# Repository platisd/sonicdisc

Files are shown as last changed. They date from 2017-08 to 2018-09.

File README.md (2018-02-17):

# SonicDisc
A 360° ultrasonic scanner that talks over I2C using an Atmega328P and eight HC-SR04 ultrasonic sensors.

sonicdisc

## Overview
SonicDisc is a sensor that allows you to sense your surroundings. It utilizes 8 ultrasound sensors (HC-SR04) placed at 45° angle from each other, that can measure distances from practically every direction. It can be used in hobby-grade automotive applications, e.g. autonomous driving, obstacle detection etc or wherever quickly determining surrounding distances is relevant.

The sensor transmits the collected data over I2C and uses a separate line to signal, with a short pulse, the existence of a new set of measurements. It can be mounted on top of an Arduino UNO or used standalone. Due to the nature of the HC-SR04 sensors, the measurements can be noisy, therefore it is suggested that they are filtered. A basic Arduino example that receives and filters the incoming data can be found in [examples/SonicDiscReader](examples/SonicDiscReader).

You can find the software running on the SonicDisc in [firmware/](firmware/), the PCB design in Eagle CAD format inside [hardware/](hardware/eagle) and more sample applications using the SonicDisc in [examples](examples/).

Read the story behind the module at [platis.solutions](https://platis.solutions/blog/2017/08/27/sonicdisc-360-ultrasonic-scanner/).

## How does it work
SonicDisc is comprised of an Atmega328P microcontroller that triggers all the ultrasound sensors at the same time, receives the echo pulses via pin change interrupts and then proceeds to calculate the detected distances. The use of interrupts, in contrast to how the HC-SR04 sensors are typically utilized, enable us to conduct all measurements at the "same" time which translates into new sets of `8` measurements every `10 milliseconds`.

As an I2C slave, whenever a new set of measurements is ready to be transmitted, a short pulse is sent over the `INT` pin, prompting the master to request the data. In other words the I2C master reading the data from the SonicDisc, does not have to poll but merely wait for the indicative signal and then make the I2C request. Despite not suggested, it is possible to use SonicDisc without connecting the `INT` pin to an interrupt, however the master will not be able to assure the existence of a new data.

## How to connect
| SonicDisc | Host MCU  |
| :----: |:----: |
| VCC |  5V |
| GND |  GND |
| SDA |  SDA |
| SCL |  SCL |
| INT |  ISR |

If you are mounting the SonicDisc on top of an Arduino UNO as a shield, you only have to (optionally but suggested) connect the `INT` signal to an ISR pin.

## I2C protocol
SonicDisc communicates using the I2C bus as a slave, meaning that it receives data from a master and responds to data requests.

### Address
SonicDisc's I2C address is currently hardcoded to `0x09`.

### Set operational state
SonicDisc has two operational states between which you can switch.

| **Action** | **Byte to send**  | **Notes** |
| :---: |:---: | :----: |
| Set state to `STANDBY` | 0x0A | SonicDisc's initial state |
| Set state to `MEASURING` | 0x0B | Set to this state to start the measurements |

**Arduino example:**
```arduino
Wire.beginTransmission(0x09);
Wire.write(0x0B); // Instruct SonicDisc to start measuring
Wire.endTransmission(0x09);
```
### Get data
SonicDisc responds to I2C requests with packages of `9` bytes that include an error code and sensor measurements. A typical package structure is described below.

Regarding the error codes, when the first byte is a `0` then everything went well and the trailing measurements are valid. If it is `1`, it means that this set of data has already been transmitted and a measurement is currently under way. You will encounter this if you poll the sensor fast enough, without taking into consideration the `INT` signal which indicates SonicDisc is ready to transmit new data. Finally, `2` designates that the module is in standby state and no measurements are being conducted.

| **Byte Index** | **Range** | **Purpose** | **Notes** |
| :----: |:----: | :----: | :----: |
| 0 |  0-2 | Error code | **0**: No error, **1**: Incomplete measurement, **2**: In standby state |
| 1 |  0-255  | Ultrasonic 0  | **0**: Error in measurement, **1**: TBD, **2-255**: Valid distance (cm) |
| 2 |  0-255  | Ultrasonic 1  | **0**: Error in measurement, **1**: TBD, **2-255**: Valid distance (cm) |
| 3 |  0-255  | Ultrasonic 2  | **0**: Error in measurement, **1**: TBD, **2-255**: Valid distance (cm) |
| 4 |  0-255  | Ultrasonic 3  | **0**: Error in measurement, **1**: TBD, **2-255**: Valid distance (cm) |
| 5 |  0-255  | Ultrasonic 4  | **0**: Error in measurement, **1**: TBD, **2-255**: Valid distance (cm) |
| 6 |  0-255  | Ultrasonic 5  | **0**: Error in measurement, **1**: TBD, **2-255**: Valid distance (cm) |
| 7 |  0-255  | Ultrasonic 6  | **0**: Error in measurement, **1**: TBD, **2-255**: Valid distance (cm) |
| 8 |  0-255  | Ultrasonic 7  | **0**: Error in measurement, **1**: TBD, **2-255**: Valid distance (cm) |

**Arduino example:**

```arduino
const unsigned int PACKET_SIZE = 9;
unsigned int packet[PACKET_SIZE] = {0};
unsigned int packetIndex = 0;
Wire.requestFrom(0x09, PACKET_SIZE);
while (Wire.available() && packetIndex < PACKET_SIZE) {
    i2cInput[packetIndex++] = Wire.read();
}
// Now the packet[] array holds the incoming data from SonicDisc
```

## Build one yourself
Below you can find the necessary components to build a SonicDisc yourself:

* [SonicDisc PCB](https://www.pcbway.com/project/shareproject/SonicDisc___A_360__ultrasonic_scanner__rev_1_.html)
* 8 x HC-SR04
* 1 x Atmega328P-PU
* 2 x 22pF capacitors
* 3 x 0.1uF capacitors
* 1 x 1206 LED
* 1 x 1206 220Ω resistor
* 3 x 4.7KΩ resistor
* 1 x 5-pin header
* 1 x 4-pin header
* 1 x tactile switch
* 1 x 16MHz oscillator
* 1 x ISCP pin header
* 1 x 10-pin stackable header
* 2 x 8-pin stackable header
* 1 x 6-pin stackable header

## Derivative works
* [Arduino Pro Mini version with single plane sensors](https://github.com/richardFirth/sonicdisc) by [richardFirth](https://github.com/richardFirth).

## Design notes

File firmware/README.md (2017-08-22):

# SonicDisc
The firmware running on the Atmega328P of the SonicDisc.

## Overview
SonicDisc sends a trigger pulse to all the attached ultrasonic sensors and then uses interrupts to log down when the echo signals were received and the detected distances are calculated. If the echo has not arrived before the specified time, then the measurement is nulled.

The results of the measurements are being made available over the I2C interface when they are being sent as a package along with an error code. Additionally, a short pulse (3 μsec) is generated in order to notify other microcontrollers that new data are available.

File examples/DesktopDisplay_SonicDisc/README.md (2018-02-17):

# DesktopDisplay_SonicDisc
This Processing3 sketch provides a visual interface for the data produced by SonicDiskReader. Connect an arduino with a SonicDisc to the computer, and then open the processing sketch. Use the number keys to select the COM port for the arduino, and the output data from SonicDiskReader will be displayed in a ring.

The distance of each circle will be proportional to the distance from the SonicDisc.

Processing3 can be downloaded from https://processing.org/. Then this sketch can be run.

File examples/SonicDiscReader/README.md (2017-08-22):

# Sonic Disc Reader
A sample Arduino sketch that demonstrates how to use the SonicDisc when attached via I2C.

Primarily, it is shown how to:
* Initiate SonicDisc measurements
* Read data
* Filter data based on variance

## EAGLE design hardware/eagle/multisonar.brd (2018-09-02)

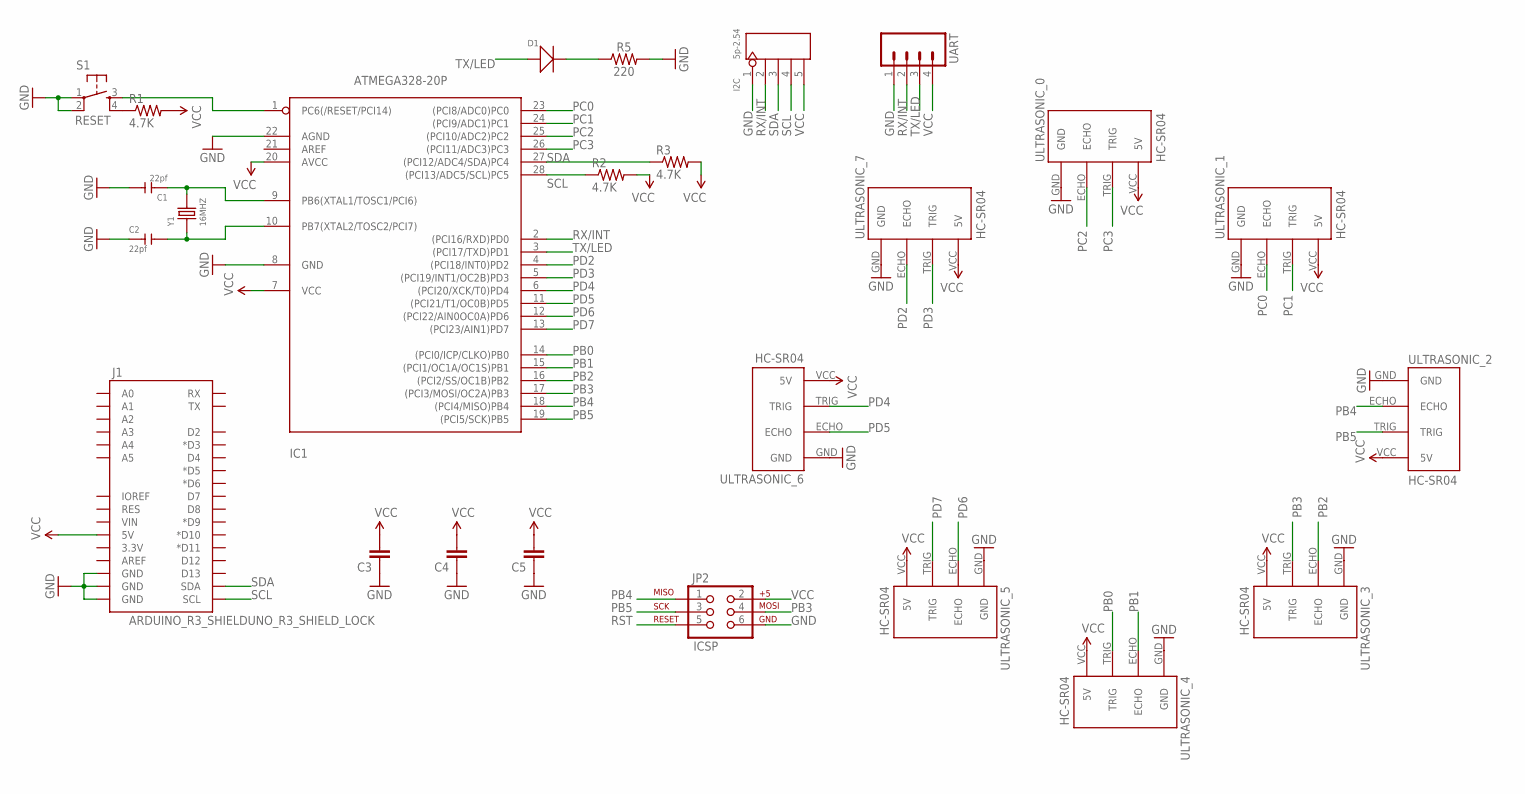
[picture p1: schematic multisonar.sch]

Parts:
C1, C2: 22pf; CERAMIC-2.54
C3, C4, C5: 0.1UF-50V-20%(PTH)KIT-EZ; CAP-PTH-SMALL-KIT
D1: DIODE'1206'; SOD-123
I2C: 5p-2.54; H5-2.54
IC1: ATMEGA328-20P; DIL28-3
J1: ARDUINO_R3_SHIELDUNO_R3_SHIELD_LOCK; UNO_R3_SHIELD_LOCK
JP2: ICSP; 2X3_LOCK
R1, R2, R3: 4.7K; AXIAL-0.3EZ
R5: 220; 1206
S1: RESET; TAC-SWITCH-PTH
UART: M04PTH; 1X04
ULTRASONIC_0, ULTRASONIC_1, ULTRASONIC_2, ULTRASONIC_3, ULTRASONIC_4, ULTRASONIC_5, ULTRASONIC_6, ULTRASONIC_7: HC-SR04; HC-SR04_FOOTPRINT
Y1: 16MHZ; HC49US

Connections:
GND: C1.2, C2.1, C3.1, C4.1, C5.1, I2C.1, IC1.8 (GND), IC1.22 (AGND), J1.GND@0 (GND), J1.GND@1 (GND), J1.GND@2 (GND), JP2.6, R5.2, S1.1, S1.2, UART.1, ULTRASONIC_0.GND, ULTRASONIC_1.GND, ULTRASONIC_2.GND, ULTRASONIC_3.GND, ULTRASONIC_4.GND, ULTRASONIC_5.GND, ULTRASONIC_6.GND, ULTRASONIC_7.GND
unnamed: R1.P$1 (1), S1.4
unnamed: D1.-, R5.1
unnamed: C1.1, IC1.9 (PB6(XTAL1/TOSC1/PCI6)), Y1.2
unnamed: C2.2, IC1.10 (PB7(XTAL2/TOSC2/PCI7)), Y1.1
PB0: IC1.14 ((PCI0/ICP/CLKO)PB0), ULTRASONIC_4.TRIG
PB1: IC1.15 ((PCI1/OC1A/OC1S)PB1), ULTRASONIC_4.ECHO
PB2: IC1.16 ((PCI2/SS/OC1B)PB2), ULTRASONIC_3.ECHO
PB3: IC1.17 ((PCI3/MOSI/OC2A)PB3), JP2.4, ULTRASONIC_3.TRIG
PB4: IC1.18 ((PCI4/MISO)PB4), JP2.1, ULTRASONIC_2.ECHO
PB5: IC1.19 ((PCI5/SCK)PB5), JP2.3, ULTRASONIC_2.TRIG
PC0: IC1.23 ((PCI8/ADC0)PC0), ULTRASONIC_1.ECHO
PC1: IC1.24 ((PCI9/ADC1)PC1), ULTRASONIC_1.TRIG
PC2: IC1.25 ((PCI10/ADC2)PC2), ULTRASONIC_0.ECHO
PC3: IC1.26 ((PCI11/ADC3)PC3), ULTRASONIC_0.TRIG
PD2: IC1.4 ((PCI18/INT0)PD2), ULTRASONIC_7.ECHO
PD3: IC1.5 ((PCI19/INT1/OC2B)PD3), ULTRASONIC_7.TRIG
PD4: IC1.6 ((PCI20/XCK/T0)PD4), ULTRASONIC_6.TRIG
PD5: IC1.11 ((PCI21/T1/OC0B)PD5), ULTRASONIC_6.ECHO
PD6: IC1.12 ((PCI22/AIN0OC0A)PD6), ULTRASONIC_5.ECHO
PD7: IC1.13 ((PCI23/AIN1)PD7), ULTRASONIC_5.TRIG
RST: IC1.1 (PC6(/RESET/PCI14)), JP2.5, S1.3
RX/INT: I2C.2, IC1.2 ((PCI16/RXD)PD0), UART.2
SCL: I2C.4, IC1.28 ((PCI13/ADC5/SCL)PC5), J1.SCL, R2.P$1 (1)
SDA: I2C.3, IC1.27 ((PCI12/ADC4/SDA)PC4), J1.SDA, R3.P$1 (1)
TX/LED: D1.+, IC1.3 ((PCI17/TXD)PD1), UART.3
VCC: C3.2, C4.2, C5.2, I2C.5, IC1.7 (VCC), IC1.20 (AVCC), J1.5V, JP2.2, R1.P$2 (2), R2.P$2 (2), R3.P$2 (2), UART.4, ULTRASONIC_0.VCC (5V), ULTRASONIC_1.VCC (5V), ULTRASONIC_2.VCC (5V), ULTRASONIC_3.VCC (5V), ULTRASONIC_4.VCC (5V), ULTRASONIC_5.VCC (5V), ULTRASONIC_6.VCC (5V), ULTRASONIC_7.VCC (5V)

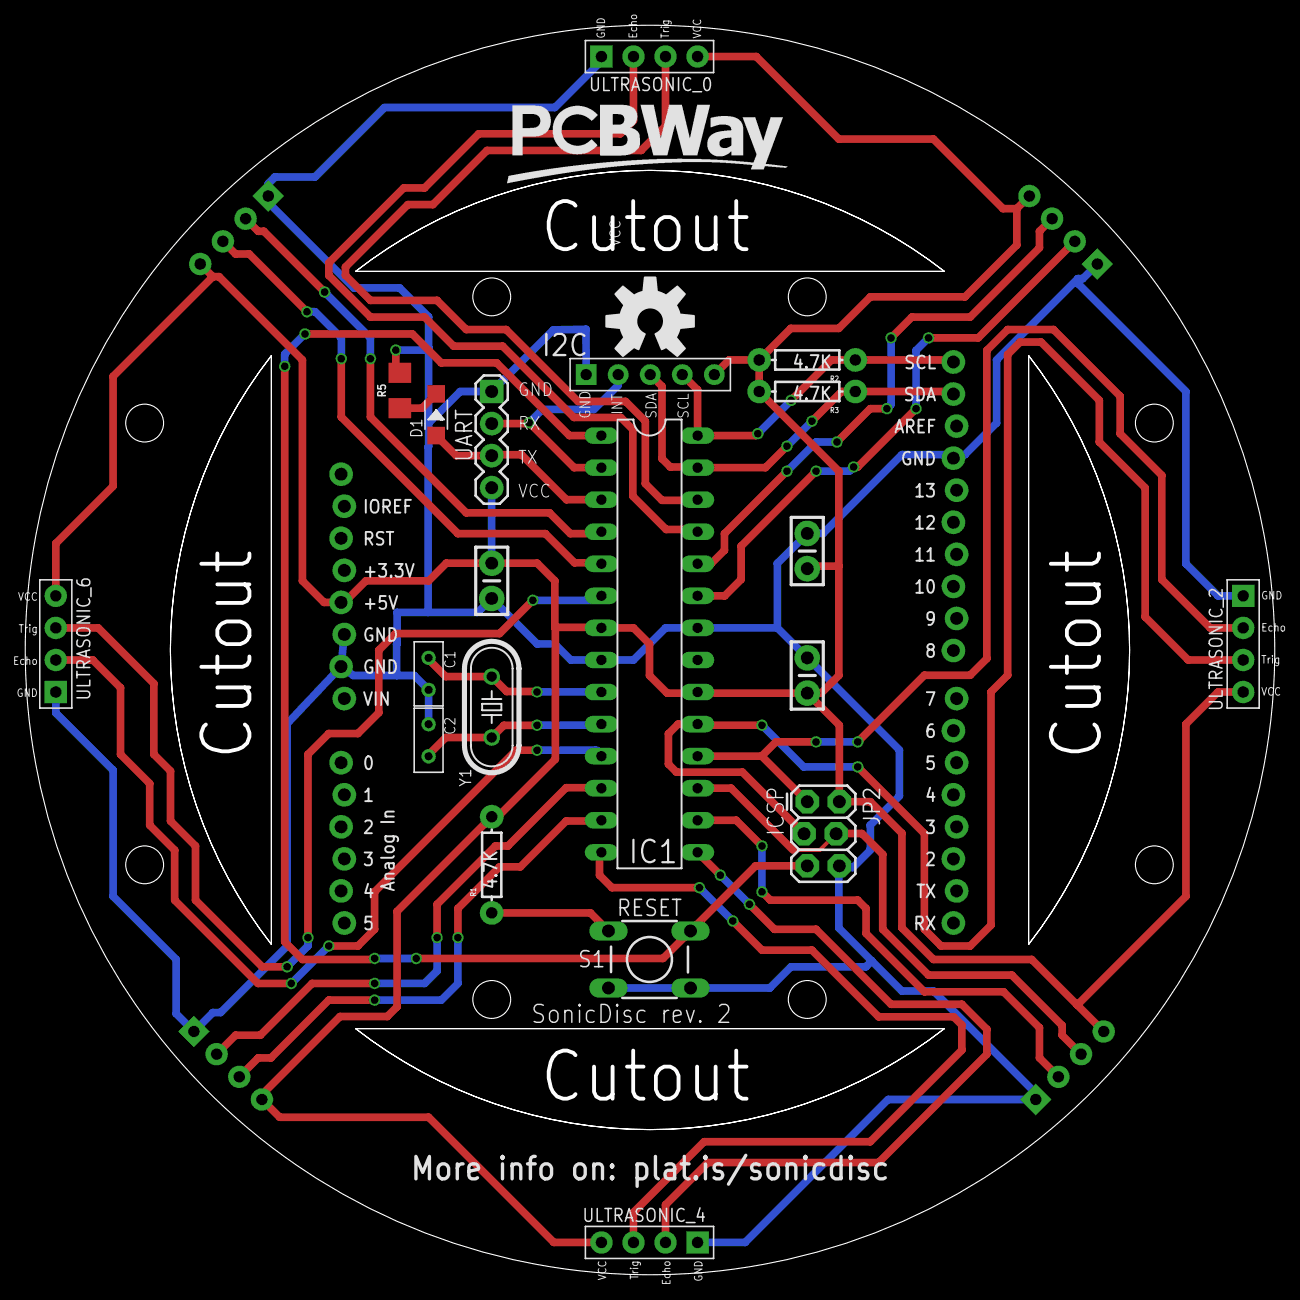
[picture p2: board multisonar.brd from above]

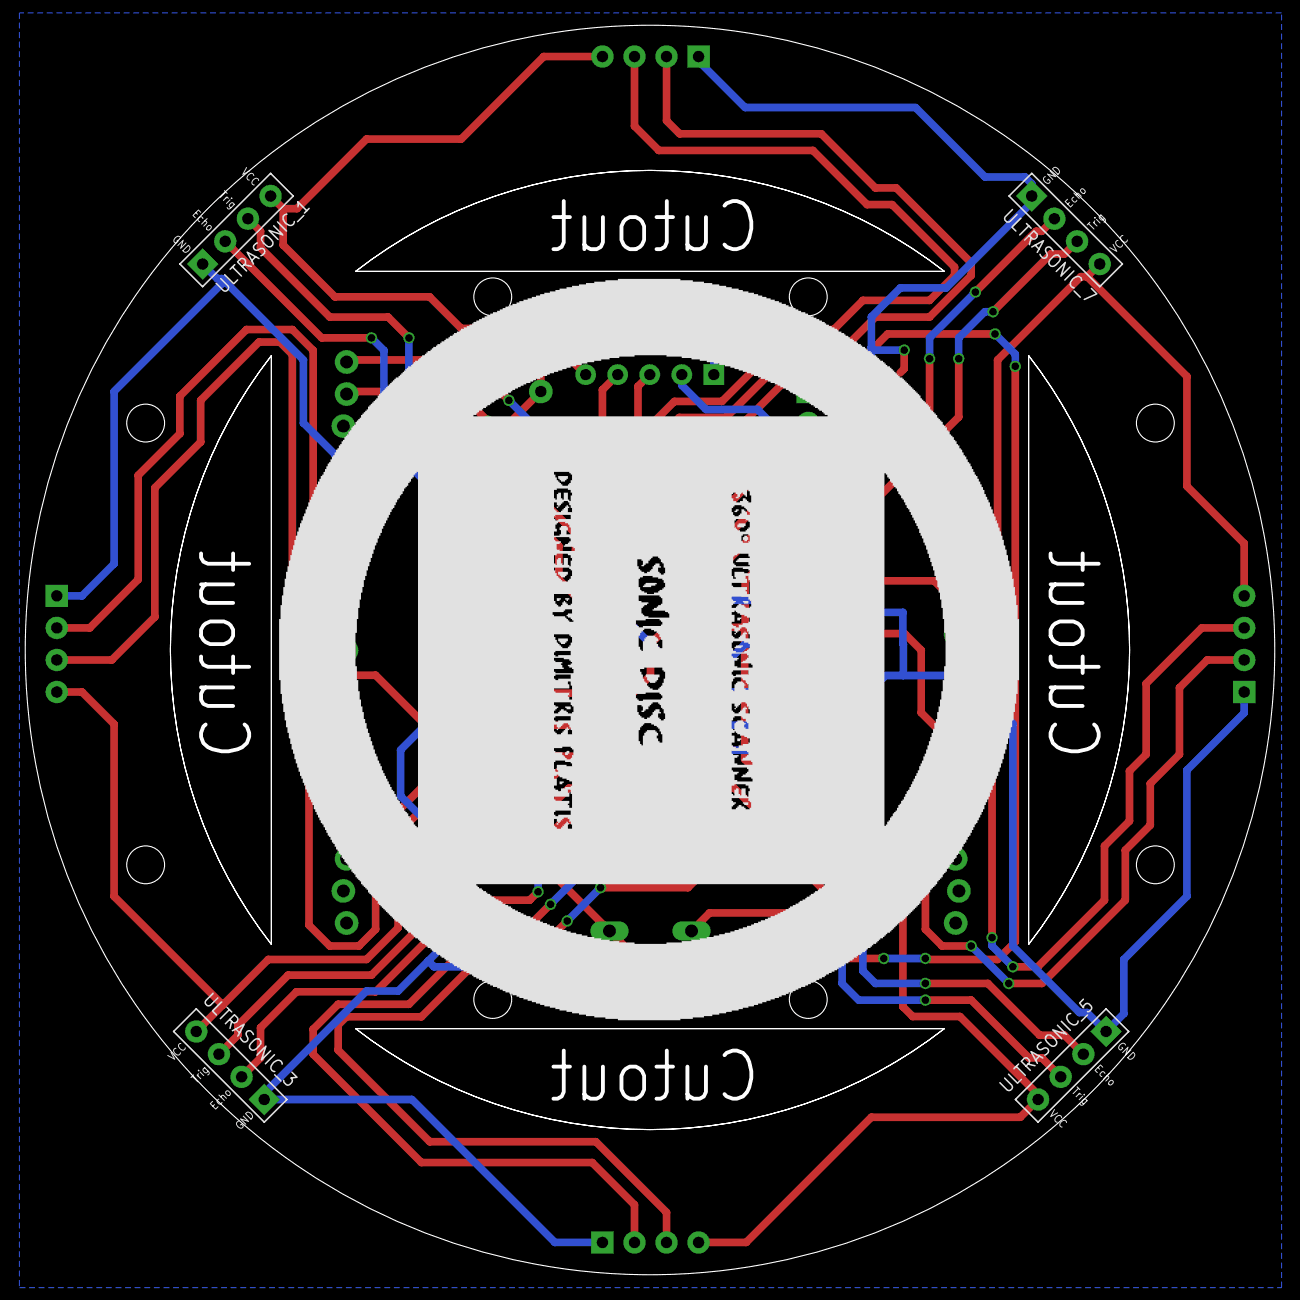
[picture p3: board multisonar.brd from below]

Board: 2 copper layers, 99.0 x 99.0 mm, 26 parts (4 on the bottom side), 27 nets.

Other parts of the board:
U$1: OSHW-LOGO-L

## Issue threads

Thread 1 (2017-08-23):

Uno's DC jack is in the way when mounted

platisd, 2017-08-23:
When the SonicDisc is mounted on top of an Arduino UNO the UNO's DC jack touches one of the sensors (Ultrasonic 7). Moving the footprint of the sensor a few millimeters outward should fix the problem.

Closed 2017-11-11.

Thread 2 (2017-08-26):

Reset button for host Arduino

platisd, 2017-08-26:
As an Arduino user I want to be able to reset my Arduino through the SonicDisc so to be able to easily restart the sketches.

SonicDisc is large enough to cover the reset button in the Arduino UNO and makes it harder to access.

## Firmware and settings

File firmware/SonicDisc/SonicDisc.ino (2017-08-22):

#include <stdint.h>
#include <Wire.h>
#include "SonicSensor.h"

const uint8_t NUM_OF_SENSORS = 8; // The number of sonic sensors on the disc
const uint8_t I2C_PACKET_SIZE = NUM_OF_SENSORS + 1; // The size of each I2C transmission in bytes
const uint8_t SONIC_DISC_I2C_ADDRESS = 0x09; // The address to assume as an I2C slave
// The pin to trigger an interrupt signal on the master MCU
// to indicate that a measurement is ready to be transmitted.
// It is set HIGH when there are data to be fetched and LOW otherwise.
const uint8_t INT_PIN = 0; // Note that this is also the RX pin
// The pin connected to the on-bard LED for debugging
const uint8_t LED_PIN = 1; // Note that this is also the TX pin
// How often the measurements should take place (in milliseconds)
const unsigned long MEASUREMENT_INTERVAL = 10;
const unsigned long STANDBY_BLINK_INTERVAL = 2000; // Frequency to blink the onboard LED when in standby
const unsigned long MEASURING_BLINK_INTERVAL = 100; // Frequency to blink the onboard LED when measuring
volatile bool newDataToSend = false; // Flag indicating a new I2C packet
volatile bool justWentToStandbyMode = false; // Flag to indicate we just transitioned to STANDBY mode

// Sonic Disc's operational states
enum State {
    STANDBY, // MCU and sensors are on but no measurements are being made
    MEASURING // Sonic Disc is conducting measurements using the sensors
};

volatile State currentState = STANDBY;

// Values to be received via I2C from master
enum I2C_RECEIPT_CODE {
    STATE_TO_STANDBY = 0x0A,
    STATE_TO_MEASURING = 0x0B
};

// Error codes to be transmitted via I2c to the master
enum I2C_ERROR_CODE {
    NO_ERROR,
    IN_STANDBY,
    INCOMPLETE_MEASUREMENT
};

// ISR vectors
enum Vector {
    VECTOR_0, // PCINT0_vect
    VECTOR_1, // PCINT1_vect
    VECTOR_2 // PCINT2_vect
};

// The Sonic Disc pin mapping of sensors
// Sonic Sensors are defined as SonicSensor(trigger pin, echo pin)
SonicSensor sensors[NUM_OF_SENSORS] = {
    SonicSensor(A3, A2),  // Ultrasonic_0 on the Sonic Disc
    SonicSensor(A1, A0),  // Ultrasonic_1
    SonicSensor(13, 12),  // Ultrasonic_2
    SonicSensor(11, 10),  // Ultrasonic_3
    SonicSensor(8, 9),    // Ultrasonic_4
    SonicSensor(7, 6),    // Ultrasonic_5
    SonicSensor(4, 5),    // Ultrasonic_6
    SonicSensor(3, 2)     // Ultrasonic_7
};

/**
 * Handles the echo signal from an ultrasonic sensor.
 * To be called from within an interrupt, it checks all the echo
 * pins to see if any of them is HIGH or LOW and updates the echo
 * pulse times of the respective sensor.
 * If a pulse has already been set, then the new value is ignored.
 * @param intVector The vector that the interrupt originated from
 */
void handleEcho(Vector intVector) {
    // We only care for interrupt signals while in measuring mode
    if (currentState != MEASURING) return;
    // Determine which vector the interrupt originated from
    // so we only check signals from those specific sensors
    int sensorsInVector[3] = {0}; // We have up to 3 sensors in each vector
    switch (intVector) {
        case VECTOR_0:
            // Ultrasonics 2, 3, 4 are on PCINT0_vect
            sensorsInVector[0] = 2;
            sensorsInVector[1] = 3;
            sensorsInVector[2] = 4;
            break;
        case VECTOR_1:
            // Ultrasonics 0, 1 are on PCINT1_vect
            sensorsInVector[0] = 0;
            sensorsInVector[1] = 1;
            sensorsInVector[2] = 1; // For simplicity
            break;
        case VECTOR_2:
            // Ultrasonics 5, 6, 7 are on PCINT2_vect
            sensorsInVector[0] = 5;
            sensorsInVector[1] = 6;
            sensorsInVector[2] = 7;
            break;
        default:
            break; // We should not be here
    }

    // Iterate through the specific vector's ultrasonic echo pins
    for (int i : sensorsInVector) {
        // If a pin is HIGH, it means that a pulse
        // is either just starting or has previously started.
        // We only care about the former.
        if (digitalRead(sensors[i].getEchoPin()) == HIGH) {
            // We only care for newly generated pulses and not ones
            // we have handled before.
            if (sensors[i].getStartOfPulse() == 0) {
                sensors[i].setStartOfPulse(micros());
            }
        } else {
            // If a pin is LOW, it means that a pulse has just ended,
            // has already ended or not started. We only care about
            // the first case. We can determine this by pulses which
            // we have not handled before AND that have already started
            if (sensors[i].getEndOfPulse() == 0 && sensors[i].getStartOfPulse() != 0) {
                sensors[i].setEndOfPulse(micros());
            }
        }
    }
}

/**
 * Hook for pin change interrupt of PCINT0 vector
 * Pins: D8 to D13
 */
ISR (PCINT0_vect) {
    handleEcho(VECTOR_0);
}

/**
 * Hook for pin change interrupt of PCINT1 vector
 * Pins: A0 to A5
 */
ISR(PCINT1_vect) {
    handleEcho(VECTOR_1);
}

/**
 * Hook for pin change interrupt of PCINT2 vector
 * Pins: D0 to D7
 */
ISR (PCINT2_vect) {
    handleEcho(VECTOR_2);
}

/**
 * Method to set up change interrupt for the specified pin
 * @param pin The Arduino-like name of the pin
 */
void setupChangeInterrupt(uint8_t pin) {
    pinMode(pin, INPUT);
    // Enable interrupt for pin
    *digitalPinToPCMSK(pin) |= bit(digitalPinToPCMSKbit(pin));
    // Clear any outstanding interrupt
    PCIFR |= bit(digitalPinToPCICRbit(pin));
    // Enable interrupt for the pin's group
    PCICR |= bit(digitalPinToPCICRbit(pin));
}

/**
 * Callback for incoming I2C requests by transmiting the collected measurements.
 * A packet of I2C_PACKET_SIZE bytes is sent upon each request. The first byte stands
 * for the error code, while the rest are the values estimated using
 * the ultrasonic sensor readings. The order of the readings is clockwise.
 * For example, a typical package looks like this:
 * |error|us_0|us_1|us_2|us_3|us_4|us_5|us_6|us_7|
 *
 * Error code values:   NO_ERROR                | No error
 *                      INCOMPLETE_MEASUREMENT  | Incomplete measurement
 *                      IN_STANDBY              | In standby state
 *
 * Sensor values:       0       | Error in measurement (e.g. ping timeout)
 *                      1       | TBD
 *                      2-255   | Valid measurement (in cm)
 */
void handleRequests() {
    uint8_t packet[I2C_PACKET_SIZE] = {0};

    // Determine the error code
    if (currentState == STANDBY) {
        packet[0] = IN_STANDBY;
    } else if (!newDataToSend) {
        packet[0] = INCOMPLETE_MEASUREMENT;
    } else {
        packet[0] = NO_ERROR;
    }

    // Populate the packet with ultrasonic distances
    for (int i = 0, j = 1; i < NUM_OF_SENSORS && j < I2C_PACKET_SIZE; i++, j++) {
        packet[j] = sensors[i].getDistance();
    }

    // Send packet via I2C
    Wire.write(packet, I2C_PACKET_SIZE);
    newDataToSend = false;
}

/**
 * Callback for incoming I2C receptions of data from the master as illustrated below.
 *
 * Request              |   Action
 * STATE_TO_STANDBY         Set state to standby (stop measurements)
 * STATE_TO_MEASURING       Start measuring
 *
 * @param numOfBytes The number of bytes expected to be received
 */
void handleReceipts(int numOfBytes) {
    if (Wire.available()) {
        char masterCommand = Wire.read();
        switch (masterCommand) {
            case STATE_TO_STANDBY:
                currentState = STANDBY;
                justWentToStandbyMode = true;
                break;
            case STATE_TO_MEASURING:
                currentState = MEASURING;
            default:
                break;
        }
    }
}

/**
 * Check to see if it is OK to start a new cycle of measurements
 * based on the current time and the measurement interval.
 * @param  currentTime The current time in milliseconds to be compared
 *                     with the last time that a measurement took place.
 * @return             True if is time to conduct a new measurement and
 *                     False otherwise
 */
bool isTimeToMeasure(unsigned long currentTime) {
    static unsigned long previousMeasurement = 0;
    bool isGoodTimeToMeasure = false;
    if (currentTime - previousMeasurement >= MEASUREMENT_INTERVAL) {
        isGoodTimeToMeasure = true;
        previousMeasurement = currentTime;
    }
    return isGoodTimeToMeasure;
}

/**
 * Will set all trigger pins to the specified state at once.
 * @param signalState LOW
 *                    HIGH
 */
void setTriggerPinsTo(uint8_t signalState) {
    switch (signalState) {
        case LOW:
            PORTB &= B11010110; // Set pins 8, 11, 13 LOW
            PORTC &= B11110101; // Set pins A1, A3 LOW
            PORTD &= B01100111; // Set pins D3, D4, D7 LOW
            break;
        case HIGH:
            // Port B handles D8 to D13
            PORTB |= B00101001; // Set pins 8, 11, 13 HIGH
            // Port C handles A0 to A5
            PORTC |= B00001010; // Set pins A1, A3 HIGH
            // Port D handles D0 to D7
            PORTD |= B10011000; // Set pins D3, D4, D7 HIGH
            break;
        default:
            break;
    }
}

/**
 * Triggers all sensors at once, using port manipulation for less
 * computation cycles. This is done by sending a pulse with a width
 * of 10 microseconds.
 */
void triggerSensors() {
    // Briefly set the trigger pins to LOW to get a cleaner signal
    setTriggerPinsTo(LOW);
    delayMicroseconds(3);

    // Set all ultrasonic trigger pins to HIGH at the same time
    setTriggerPinsTo(HIGH);
    // Keep the signal HIGH for 10 microseconds
    delayMicroseconds(10);

    // Set the trigger pins back to LOW
    setTriggerPinsTo(LOW);
}

/**
 * Sets the LED blinking frequency depending on the current operational state
 */
void blinkToIndicateState() {
    static unsigned long previousBlink = 0;
    static bool currentLedState = false;

    // Determine the blinking interval
    unsigned long blinkInterval = 0;
    switch (currentState) {
        case STANDBY:
            blinkInterval = STANDBY_BLINK_INTERVAL;
            break;
        case MEASURING:
            blinkInterval = MEASURING_BLINK_INTERVAL;
            break;
        default:
            break;
    }

    // Blink based on the operational state
    unsigned long currentTime = millis();
    if (currentTime - previousBlink >= blinkInterval) {
        previousBlink = currentTime;
        currentLedState = !currentLedState;
        digitalWrite(LED_PIN, currentLedState);
    }
}

/**
 * Run once on boot or after a reset
 */
void setup() {
    // Set up ultrasonic sensor pins
    for (int i = 0; i < NUM_OF_SENSORS; i++){
        // Set up change interrupts for all the echo pins
        setupChangeInterrupt(sensors[i].getEchoPin());
        // Set up all trigger pins as outputs
        pinMode(sensors[i].getTriggerPin(), OUTPUT);
    }
    // Set up the interrupt signal and led pins
    pinMode(INT_PIN, OUTPUT);
    pinMode(LED_PIN, OUTPUT);
    // Set up the I2C bus and join it as a slave with address 9
    Wire.begin(SONIC_DISC_I2C_ADDRESS);
    // Set up callback for I2C requests
    Wire.onRequest(handleRequests);
    // Set up callback for I2C receipts
    Wire.onReceive(handleReceipts);
}

/**
 * Run continuously after setup()
 */
void loop() {
    blinkToIndicateState();
    switch(currentState) {
        case STANDBY:
            // Determine if we just entered standby to reset the sensors
            if (justWentToStandbyMode) {
                // Reset the measurements so there are no leftover data
                for (int i = 0; i < NUM_OF_SENSORS; i++) {
                    sensors[i].reset();
                }
                justWentToStandbyMode = false;
            }
            break;
        case MEASURING:
            if (isTimeToMeasure(millis())) {
                // Disable the interrupts so we can prepare to calculate
                // the distances and then we are ready to start a new
                // set of measurements.
                noInterrupts();             // Begin critical section
                for (int i = 0; i < NUM_OF_SENSORS; i++) {
                    // Copy the (volatile) start and end times of the pulses
                    // so that we can begin immediately measuring again,
                    // while distances of the (now previous) measurements are
                    // being calculated.
                    sensors[i].prepareToCalculate();
                    // Then reset previous the echoes so we can
                    // conduct new measurements
                    sensors[i].reset();
                }
                // Finally start a new set of measurements
                // by triggering all sensors at once
                triggerSensors();
                interrupts();               // End critical section

                // Now that we are certain that our measurements are consistent
                // time-wise, calculate the distance.
                for (int i = 0; i < NUM_OF_SENSORS; i++) {
                    // Calculate distance for each sensor.
                    // Will also timeout any pending measurements
                    sensors[i].calculateDistance();
                }
                // Send a short pulse to signal that we have a new set of measurements
                noInterrupts();             // Begin critical section
                // Make sure that no interrupts (i.e. I2C) occur between setting
                // the master's interrupt pin HIGH and raising the new data flag.
                digitalWrite(INT_PIN, HIGH);
                delayMicroseconds(3);
                digitalWrite(INT_PIN, LOW);
                newDataToSend = true;
                interrupts();               // End critical section
            }
            break;
        default:
            break; // We should not get here
    }
}

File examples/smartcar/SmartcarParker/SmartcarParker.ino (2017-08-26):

#include <Wire.h>
#include <stdint.h>
#include <Smartcar.h>

Car car;

const uint8_t SONIC_DISC_I2C_ADDRESS = 0x09;
const uint8_t NUM_OF_SENSORS = 8; // No. of ultrasonic sensors on SonicDisc
// The packet contains NUM_OF_MEASUREMENTS measurements and an error code
const uint8_t I2C_PACKET_SIZE = NUM_OF_SENSORS + 1;
// The number of measurements from each sensor to filter
const uint8_t MEASUREMENTS_TO_FILTER = 5;
const uint8_t INT_PIN = 2;
// The max valid variance in a set of MEASUREMENTS_TO_FILTER measurements
const unsigned int VARIANCE_THRESHOLD = 3;

// Sonic Disc's operational states
enum State {
  STANDBY, // MCU and sensors are on but no measurements are being made
  MEASURING // Sonic Disc is conducting measurements using the sensors
};

// Values to be received via I2C from master
enum I2C_RECEIPT_CODE {
  STATE_TO_STANDBY = 0x0A,
  STATE_TO_MEASURING = 0x0B
};

// Error codes to be transmitted via I2c to the master
enum I2C_ERROR_CODE {
  NO_ERROR,
  IN_STANDBY,
  INCOMPLETE_MEASUREMENT
};

// Flag to indicate the SonicDisc is ready to send a new set of data
volatile bool newData = false;

uint8_t filterIndex = 0;
uint8_t filterBuffer[MEASUREMENTS_TO_FILTER][NUM_OF_SENSORS] = {0};
uint8_t filteredMeasurements[NUM_OF_SENSORS] = {0};
bool newFilteredMeasurements = false;

// The different parking states
enum ParkingState {
  PARKING_START,        // Initial state, no obstacle has been found yet
  FIRST_OBSTACLE,       // First obstacle is detected
  BETWEEN_OBSTACLES,    // First obstacle not detected. Driving through the gap
  SECOND_OBSTACLE,      // Second obstacle is detected
  REVERSE_RIGHT,        // First parking maneuver
  REVERSE_LEFT,         // Second parking maneuver
  FINAL_POSITION_FIX,   // Going forward to be in the middle of the parking spot
  PARKING_END           // Parking has finished, remain idle
};

ParkingState parkingState = PARKING_START; // Holds the current parking state

/**
   Requests an I2C packet from the SonicDisc
   @param  i2cInput         The array that will hold the incoming packet
   @param  transmissionSize The size/length of the incoming packet
   @return                  Error code contained inside the incoming packet
*/
I2C_ERROR_CODE requestPacket(uint8_t i2cInput[], const uint8_t transmissionSize = I2C_PACKET_SIZE) {
  Wire.requestFrom(SONIC_DISC_I2C_ADDRESS, transmissionSize);
  uint8_t packetIndex = 0;
  while (Wire.available() && packetIndex < transmissionSize) {
    i2cInput[packetIndex++] = Wire.read();
  }
  return i2cInput[0]; // Return the packet's error code
}

/**
   Sends the supplied byte to the SonicDisc
   @param byteToSend The byte to be sent
*/
void sendData(uint8_t byteToSend) {
  Wire.beginTransmission(SONIC_DISC_I2C_ADDRESS);
  Wire.write(byteToSend);
  Wire.endTransmission(SONIC_DISC_I2C_ADDRESS);
}

/**
   ISR that raises a flag whenever SonicDisc is ready to transmit new data.
*/
void newSonicDiscData() {
  newData = true;
}

/*
   Adds the specified i2c packet in the buffer to be sorted later.
*/
void addInputToFilterBuffer(uint8_t i2cInput[], const uint8_t bufferIndex) {
  // Copy the whole packet (except error code) in the specified row of the buffer
  for (int i = 0, j = 1; i < NUM_OF_SENSORS; i++, j++) {
    filterBuffer[bufferIndex][i] = i2cInput[j];
  }
}

/*
    Sorts the measurements of each sensor for every cycle of measurements.
*/
void sortMeasurements() {
  // For each sensor
  for (int s = 0; s < NUM_OF_SENSORS; s++) {
    // Use bubble sort to sort all measurements throughout the cycle
    for (int i = 0; i < MEASUREMENTS_TO_FILTER - 1; i++) {
      for (int j = 0; j < MEASUREMENTS_TO_FILTER - i - 1; j++) {
        if (filterBuffer[j][s] > filterBuffer[j + 1][s]) {
          uint8_t toSwap = filterBuffer[j][s];
          filterBuffer[j][s] = filterBuffer[j + 1][s];
          filterBuffer[j + 1][s] = toSwap;
        }
      }
    }
  }
}

/*
    Filter measurements depending on the variance.
    If variance is too high for a MEASUREMENTS_TO_FILTER measurements of a sensor
    then these measurements are disregarded. Otherwise the mean value is chosen.
*/
void filterMeasurements() {
  // Go through all the measurements taken for each sensor
  for (int i = 0; i < NUM_OF_SENSORS; i++) {
    // Calculate the variance across the different measurements
    // by subtracting the first and the last element
    // of the *sorted* measurement cycle.
    int variance = filterBuffer[0][i] - filterBuffer[MEASUREMENTS_TO_FILTER - 1][i];
    if (abs(variance) > VARIANCE_THRESHOLD) {
      filteredMeasurements[i] = 0;
    } else {
      filteredMeasurements[i] = filterBuffer[MEASUREMENTS_TO_FILTER / 2][i];
    }
  }
}

void setup() {
  Wire.begin();
  Serial.begin(9600);
  attachInterrupt(digitalPinToInterrupt(INT_PIN), newSonicDiscData, RISING);
  Serial.println("Requesting packet from SonicDisc");
  uint8_t dummyInput[I2C_PACKET_SIZE] = {0}; // A throw-away array
  // Do not proceed unless the SonicDisc is in "MEASURING" state
  while (requestPacket(dummyInput, I2C_PACKET_SIZE) == IN_STANDBY) {
    Serial.println("Setting state to MEASURING");
    sendData(STATE_TO_MEASURING);
  }
  Serial.println("Communication is established and SonicDisc is measuring distances");
  car.begin();
  car.setSpeed(0);
  car.setAngle(0);
}
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

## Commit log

2017-08-21 Initial files with dimension layer
    [multisonar.brd, multisonar.sch]
2017-08-21 Add ultrasonic sensors
    [multisonar.brd, multisonar.sch]
2017-08-21 Increased spacing between components
    [multisonar.sch]
2017-08-21 New project structure and added components
    [multisonar.brd, multisonar.sch]
2017-08-21 Routed power lines
    [multisonar.brd, multisonar.sch]
2017-08-21 Added milling layer
    [multisonar.brd]
2017-08-21 Routed all components
    TO-DO: Add silk screen
    [multisonar.brd, multisonar.sch]
2017-08-21 Add initial Sonic Sensor implementation
2017-08-21 Setup change interrupt method
    Used example from https://playground.arduino.cc/Main/PinChangeInterrupt
2017-08-21 Change IRQ to INT for clarity
    It should be easier to explain to novice users
    [multisonar.brd, multisonar.sch]
2017-08-21 Add pin numbers (not Arduino-like)
2017-08-21 Add Arduino-like pins
2017-08-21 Add initial I2C interface
2017-08-21 Add states, error codes and i2c receipts
    [SonicDisc.ino]
2017-08-21 Add initial control logic for measurements
    TO-DO: Trigger all sensors at once via port manipulation
2017-08-21 Add triggering all sensors via port manipulation
2017-08-21 Handle the echo inside an interrupt
    However, just realized that this is not the way that the SR04 works. The duration of the echo PULSE should be measured instead.
    Also, set the trigger pins low for a few microseconds before sending the pulse.
2017-08-21 Corrected handling of measurements according to datasheet
    TO-DO: Narrow down the sensors to check inside the interrupts
    depending on which vector the interrupt is coming from
    [SonicDisc.ino]
2017-08-21 Check only specific sensors for echo pulse
    Depending on which interrupt vector was triggered
2017-08-21 Compose the package to send via i2c
2017-08-21 Add bottom silk screen
    Board Rev. 0, sent to PCBWay
    [multisonar.brd]
2017-08-21 Increase measurement frequency
    Since filtering will be done on the reader side,
    let's keep this fast enough.
2017-08-22 Add filtering to the incoming values
    The filter will read the specified amount of measurements
    from each sensor and then will determine whether the variance
    is too high for the measurements to be valid.
    [SonicDiscReader.ino]
2017-08-22 Add readme to SonicDiscReader sample sketch
2017-08-22 Reset sensors when going back to standby
    [SonicDisc.ino]
2017-08-23 Small refactoring when handling filtered measurements
    For better readability
2017-11-11 Increase board size to 99mm
    Fixes #1
    [multisonar.brd]
2017-11-11 Moving i2c header downwards
    So there is more space when angled headers are used
    [multisonar.brd]
2017-11-11 Use the lock package for easier soldering
    The lock arduino shield package is used to facilitate
    the headers staying in place while soldering
    [multisonar.brd, multisonar.sch]
2017-11-11 Ultrasonic position fix
    [multisonar.brd]
2017-11-11 Update link to buy rev.1 PCB
2018-02-04 add fabrication files, code, and assembly instructions
    [AcrylicRing.dxf, HCSR04_RingSection_B.brd, HCSR04_RingSection_B.sch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]
2018-02-11 restructure folders, add Processing3 sketch
    [AcrylicRing.dxf, HCSR04_RingSection_B.brd, HCSR04_RingSection_B.sch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]
2018-09-02 Add rev. 2 board
    * Move I2C header down for easier cabling through the cutout
    * Add OSH logo
    * Add PCBWay.com logo (sponsors)
    [multisonar.brd]

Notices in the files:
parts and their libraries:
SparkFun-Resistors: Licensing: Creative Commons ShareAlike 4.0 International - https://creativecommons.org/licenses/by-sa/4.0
